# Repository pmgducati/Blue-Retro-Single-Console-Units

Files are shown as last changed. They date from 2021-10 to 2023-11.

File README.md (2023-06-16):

# Blue-Retro-Single-Console-Units

This is a collection of PCBs that I made to work with darthcloud's BlueRetro Project. (https://github.com/darthcloud/BlueRetro) The PCB's were created in Eagle and I have included the Gerbers if you would like to create them yourself.

Currently I have NES, Nintendo 64, Gamecube, Sega Saturn, 3DO, PSX/PS2 and PCEngine/Turbografx 16 complete.

I have created PCB's for other supported systems (Listed Below) but have not tested them as I do not have the sytems. I have created a issue for each of the systems that I do not have to test. If you make one please comment in the related issue on any progress/problems.

I am working through Virtual Boy but need to find a cost efficient way to connect it to the Virtual Boy as I am not consolizing mine.

Here is the current status of all systems:


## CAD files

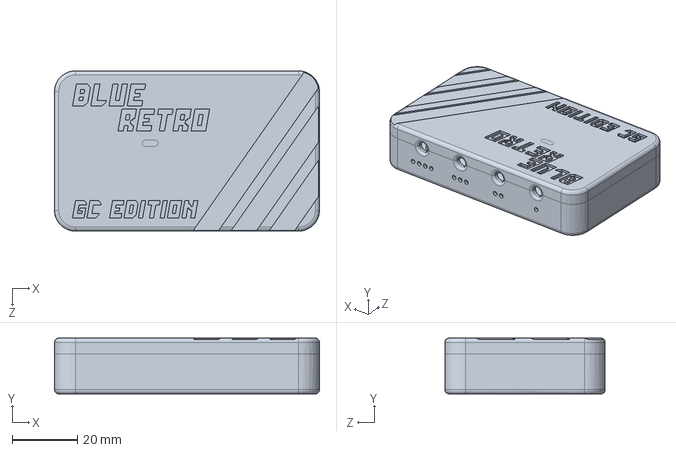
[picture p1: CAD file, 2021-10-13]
CAD/GC Housing - R2.SLDPRT
81.0 x 17.0 x 49.0 mm

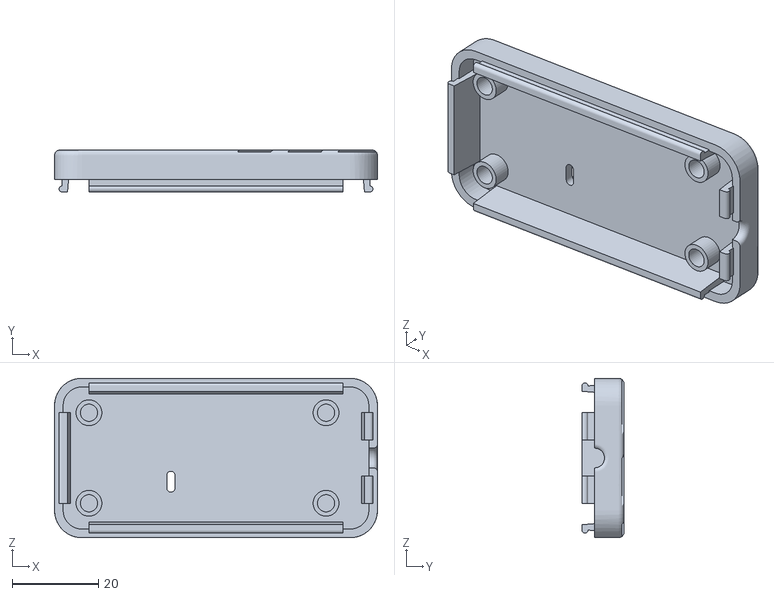
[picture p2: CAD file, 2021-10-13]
STL/3DO Top.STL
74.9 x 9.74 x 37.0

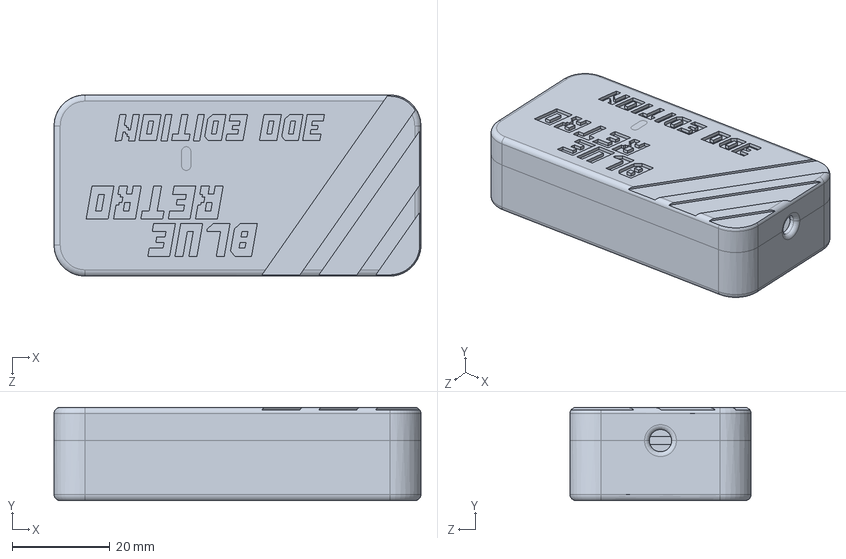
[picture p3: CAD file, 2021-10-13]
CAD/3DO Housing.SLDPRT
74.9 x 19.0 x 37.0 mm

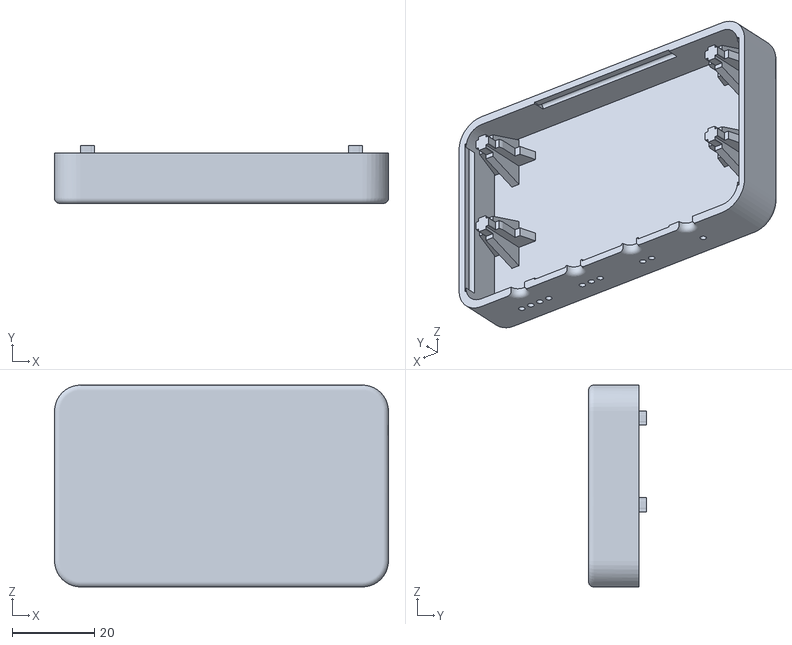
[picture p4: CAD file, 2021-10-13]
STL/GC Bottom.STL
81.0 x 14.0 x 49.0

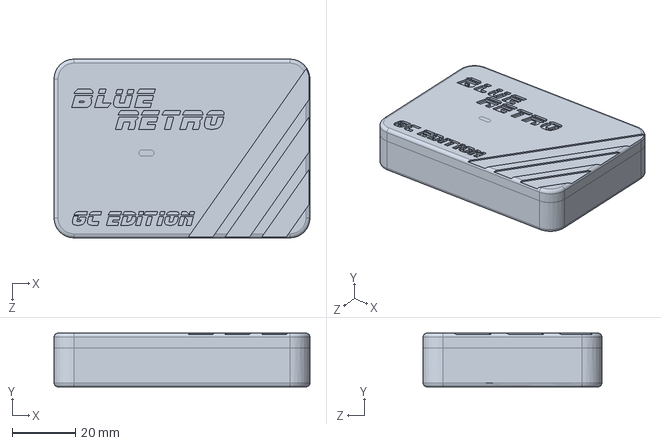
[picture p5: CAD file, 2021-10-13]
CAD/GC Housing.SLDPRT
81.0 x 17.0 x 56.6 mm

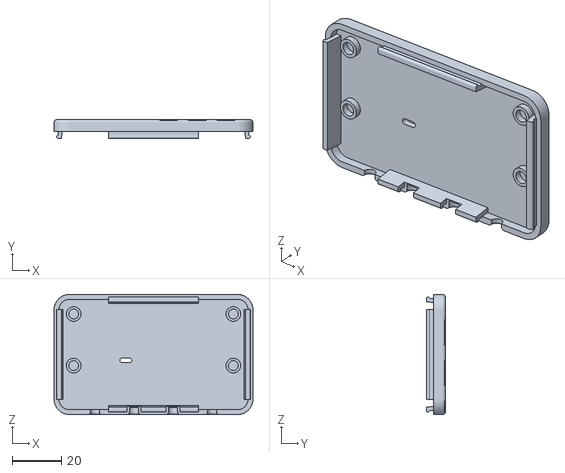
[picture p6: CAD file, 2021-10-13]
STL/GC Top.STL
81.0 x 7.75 x 49.0

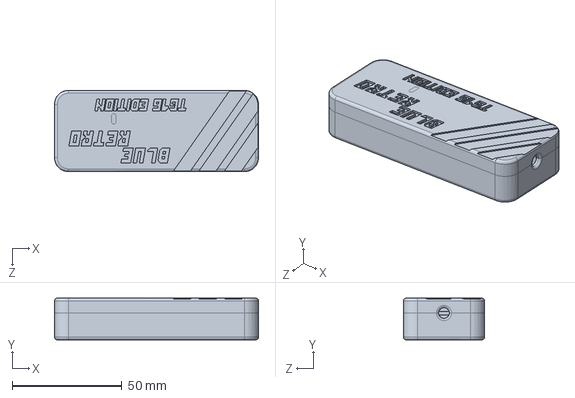
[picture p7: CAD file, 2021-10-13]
CAD/TG-16 Housing.SLDPRT
92.9 x 19.0 x 37.0 mm

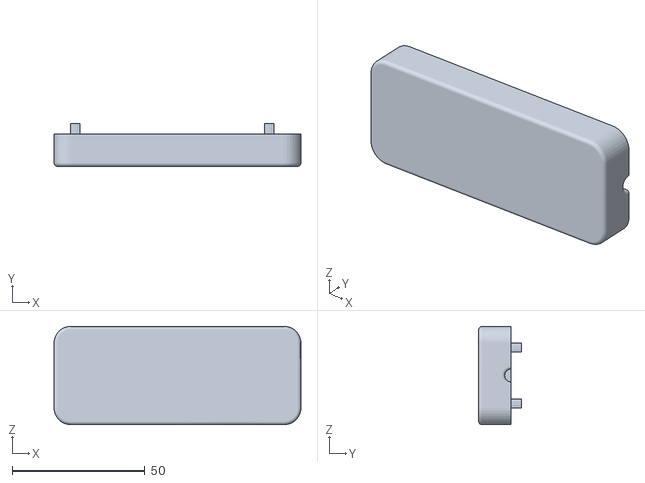
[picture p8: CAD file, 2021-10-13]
STL/TG16 Bottom.STL
92.9 x 16.0 x 37.0

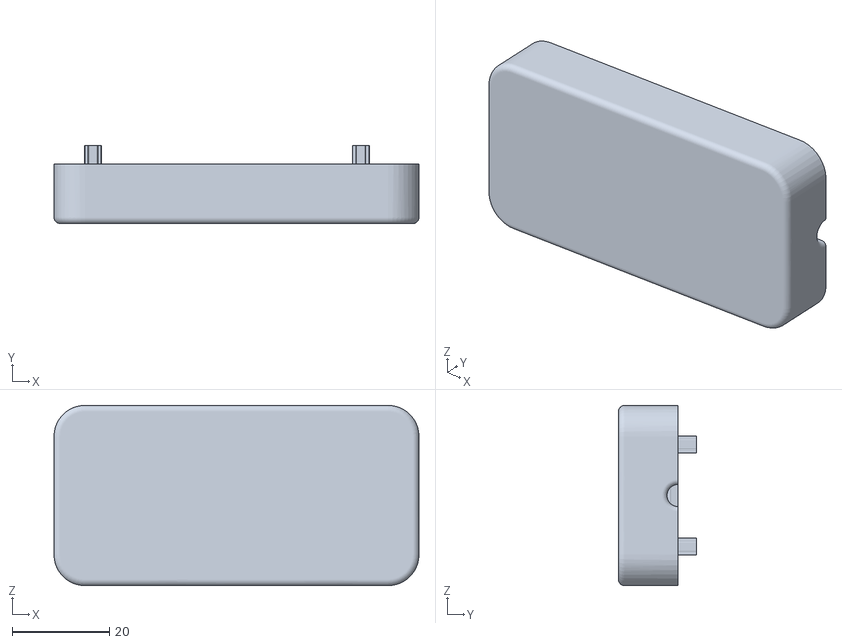
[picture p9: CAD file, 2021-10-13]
STL/3DO Bottom.STL
74.9 x 16.0 x 37.0

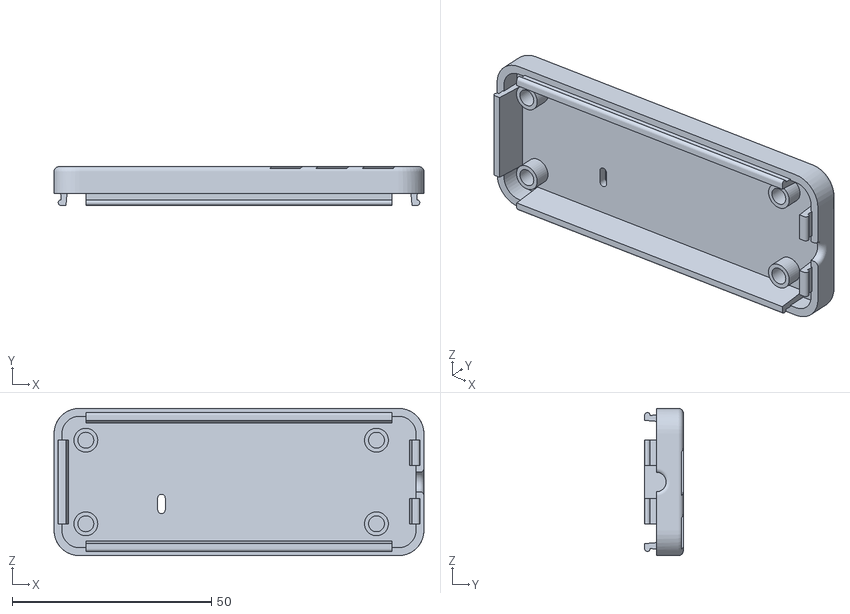
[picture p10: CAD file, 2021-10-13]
STL/TG16 Top.STL
92.9 x 9.74 x 37.0

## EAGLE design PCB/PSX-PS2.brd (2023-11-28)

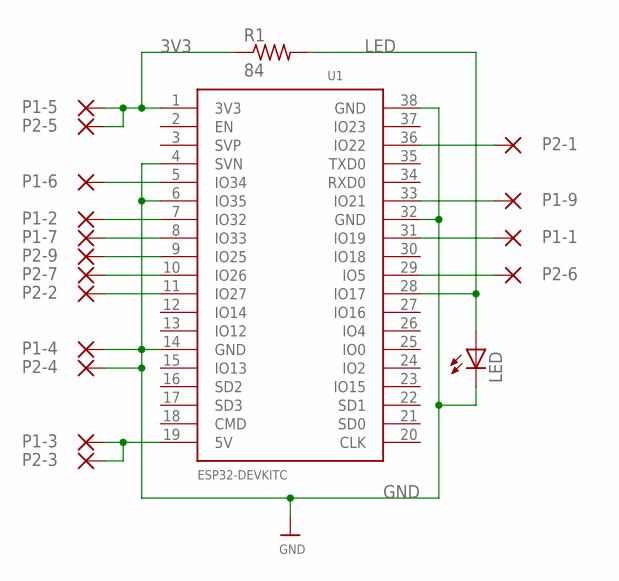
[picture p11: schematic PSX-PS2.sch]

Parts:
LED: LEDCHIPLED_1206; CHIPLED_1206
P1-1, P1-2, P1-3, P1-4, P1-5, P1-6, P1-7, P1-9, P2-1, P2-2, P2-3, P2-4, P2-5, P2-6, P2-7, P2-9: SMD5; SMD2,54-5,08
R1: 84; R1206
U1: ESP32DEVKITC; ESP32-DEVKITC

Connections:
3V3: P1-5.1, P2-5.1, R1.1, U1.1 (3V3)
8V: P1-3.1, P2-3.1, U1.19 (5V)
GND: LED.C, P1-4.1, P2-4.1, U1.4 (SVN), U1.6 (IO35), U1.14 (GND), U1.32 (GND), U1.38 (GND)
LED: LED.A, R1.2, U1.28 (IO17)
P1-1: P1-1.1, U1.31 (IO19)
P1-2: P1-2.1, U1.7 (IO32)
P1-6: P1-6.1, U1.5 (IO34)
P1-7: P1-7.1, U1.8 (IO33)
P1-9: P1-9.1, U1.33 (IO21)
P2-1: P2-1.1, U1.36 (IO22)
P2-2: P2-2.1, U1.11 (IO27)
P2-6: P2-6.1, U1.29 (IO5)
P2-7: P2-7.1, U1.10 (IO26)
P2-9: P2-9.1, U1.9 (IO25)

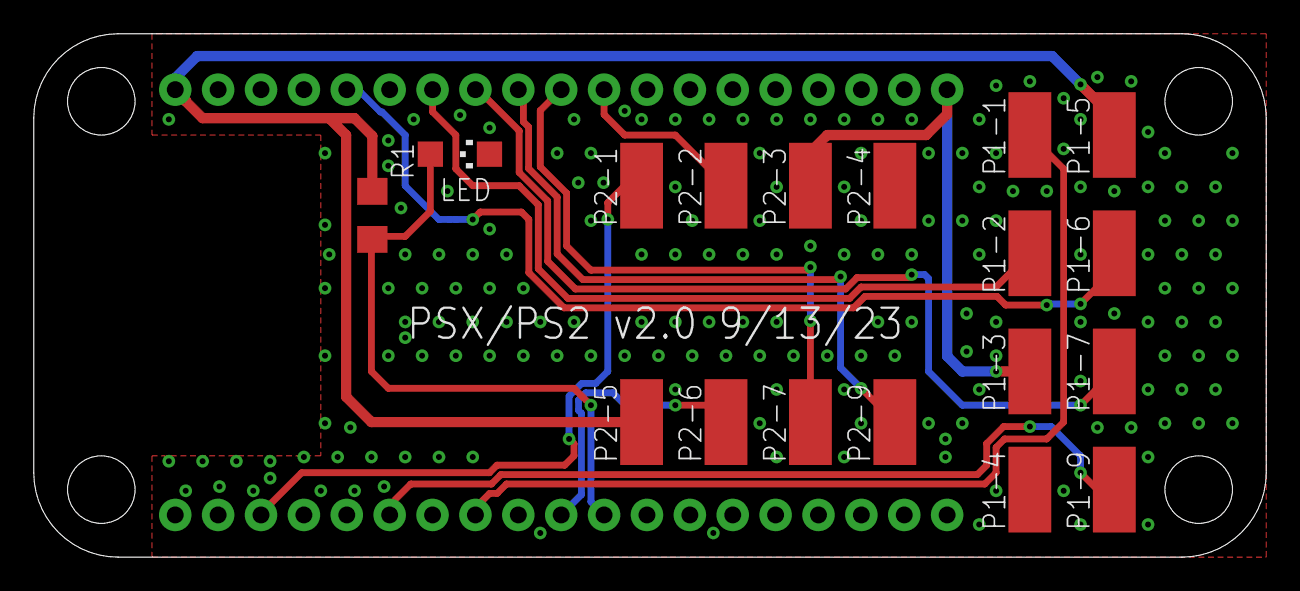
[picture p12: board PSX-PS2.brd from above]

Board: 2 copper layers, 73.0 x 31.0 mm, 19 parts (1 on the bottom side), 14 nets.

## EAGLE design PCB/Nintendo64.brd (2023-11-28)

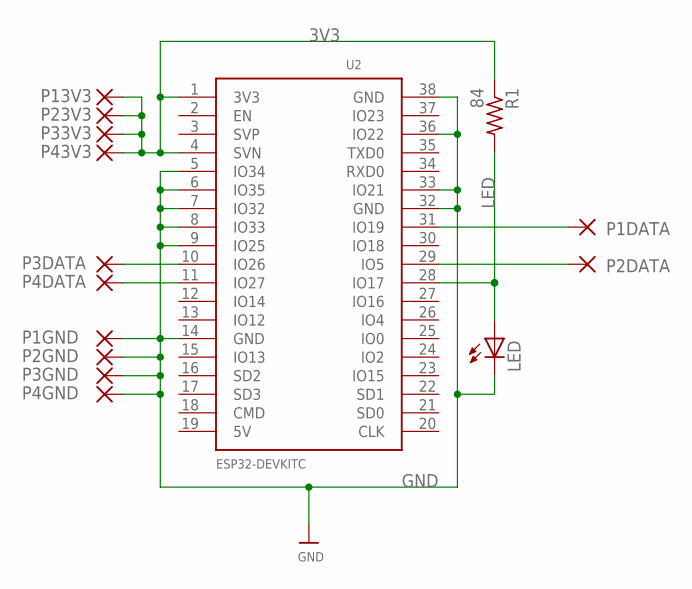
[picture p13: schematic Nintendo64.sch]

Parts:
LED: LEDCHIPLED_1206; CHIPLED_1206
P1DATA, P1GND, P2DATA, P2GND, P3DATA, P3GND, P4DATA, P4GND, P13V3, P23V3, P33V3, P43V3: SMD5; SMD2,54-5,08
R1: 84; R1206
U2: ESP32DEVKITC; ESP32-DEVKITC

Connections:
3V3: P13V3.1, P23V3.1, P33V3.1, P43V3.1, R1.1, U2.1 (3V3), U2.4 (SVN)
GND: LED.C, P1GND.1, P2GND.1, P3GND.1, P4GND.1, U2.5 (IO34), U2.6 (IO35), U2.7 (IO32), U2.8 (IO33), U2.9 (IO25), U2.14 (GND), U2.32 (GND), U2.33 (IO21), U2.36 (IO22), U2.38 (GND)
LED: LED.A, R1.2, U2.28 (IO17)
P1DATA: P1DATA.1, U2.31 (IO19)
P2DATA: P2DATA.1, U2.29 (IO5)
P3DATA: P3DATA.1, U2.10 (IO26)
P4DATA: P4DATA.1, U2.11 (IO27)

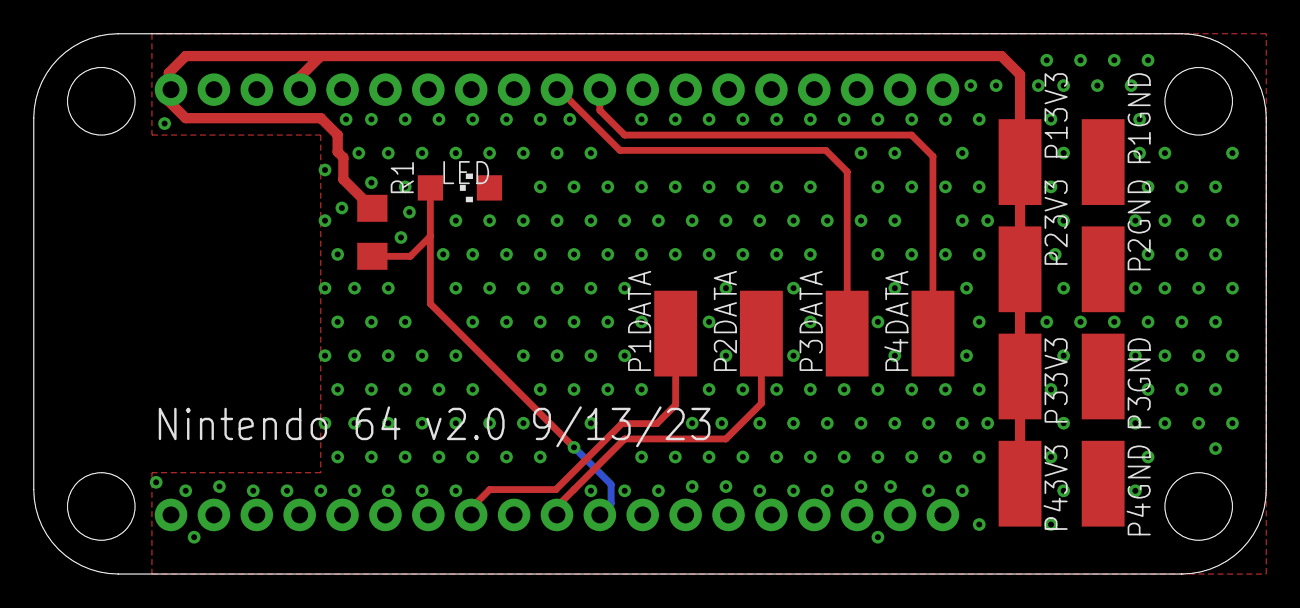
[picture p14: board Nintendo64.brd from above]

Board: 2 copper layers, 73.0 x 32.0 mm, 15 parts (1 on the bottom side), 7 nets.

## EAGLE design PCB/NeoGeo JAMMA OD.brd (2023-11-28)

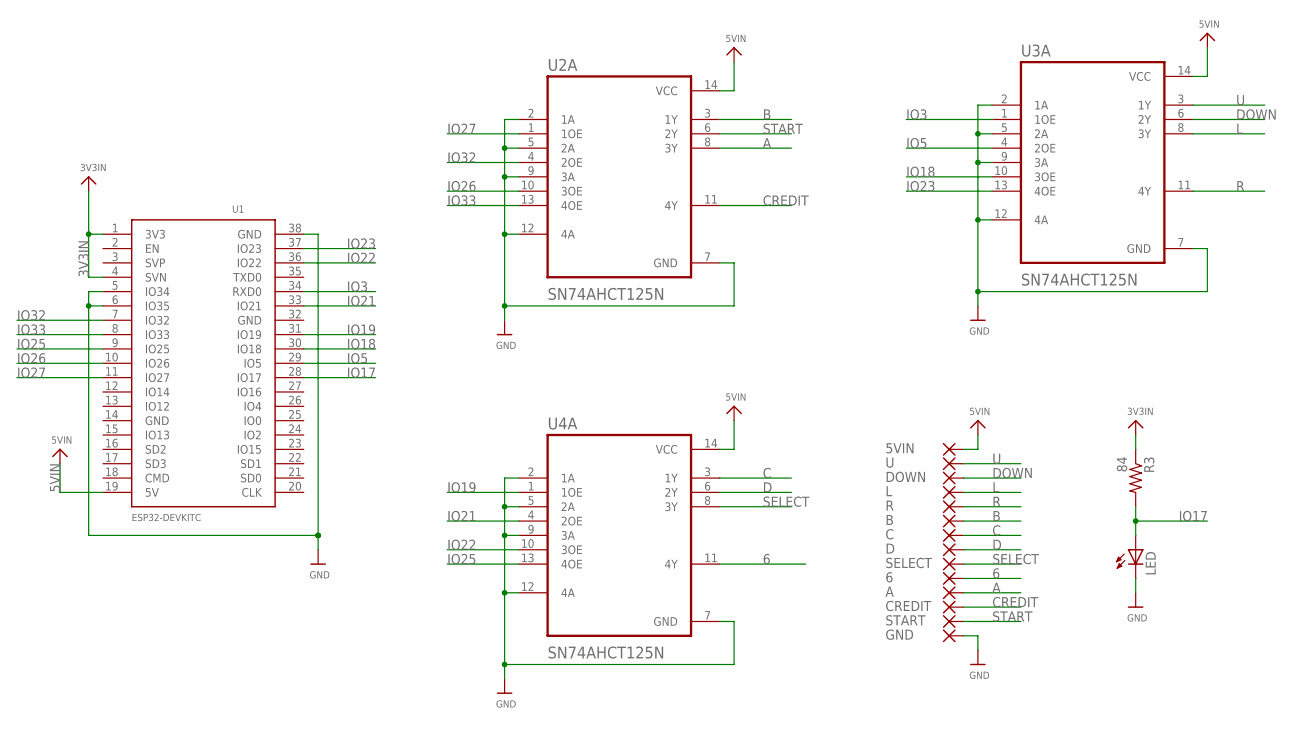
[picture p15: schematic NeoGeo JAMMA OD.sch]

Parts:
5VIN, 6: SMD5; SMD2,54-5,08
A: SMD5; SMD2,54-5,08
B: SMD5; SMD2,54-5,08
C: SMD5; SMD2,54-5,08
CREDIT: SMD5; SMD2,54-5,08
D: SMD5; SMD2,54-5,08
DOWN: SMD5; SMD2,54-5,08
GND: SMD5; SMD2,54-5,08
L: SMD5; SMD2,54-5,08
LED: LEDCHIPLED_1206; CHIPLED_1206
R: SMD5; SMD2,54-5,08
R3: 84; R1206
SELECT: SMD5; SMD2,54-5,08
START: SMD5; SMD2,54-5,08
U: SMD5; SMD2,54-5,08
U1: ESP32DEVKITC; ESP32-DEVKITC
U2A, U3A, U4A: SN74AHCT125N; DIP794W45P254L1969H508Q14

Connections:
3V3IN: R3.1, U1.1 (3V3), U1.4 (SVN)
5VIN: 5VIN.1, U1.19 (5V), U2A.14 (VCC), U3A.14 (VCC), U4A.14 (VCC)
6: 6.1, U4A.11 (4Y)
A: A.1, U2A.8 (3Y)
B: B.1, U2A.3 (1Y)
C: C.1, U4A.3 (1Y)
CREDIT: CREDIT.1, U2A.11 (4Y)
D: D.1, U4A.6 (2Y)
DOWN: DOWN.1, U3A.6 (2Y)
GND: GND.1, LED.C, U1.5 (IO34), U1.6 (IO35), U1.38 (GND), U2A.2 (1A), U2A.5 (2A), U2A.7 (GND), U2A.9 (3A), U2A.12 (4A), U3A.2 (1A), U3A.5 (2A), U3A.7 (GND), U3A.9 (3A), U3A.12 (4A), U4A.2 (1A), U4A.5 (2A), U4A.7 (GND), U4A.9 (3A), U4A.12 (4A)
IO3: U1.34 (RXD0), U3A.1 (1OE)
IO5: U1.29 (IO5), U3A.4 (2OE)
IO17: LED.A, R3.2, U1.28 (IO17)
IO18: U1.30 (IO18), U3A.10 (3OE)
IO19: U1.31 (IO19), U4A.1 (1OE)
IO21: U1.33 (IO21), U4A.4 (2OE)
IO22: U1.36 (IO22), U4A.10 (3OE)
IO23: U1.37 (IO23), U3A.13 (4OE)
IO25: U1.9 (IO25), U4A.13 (4OE)
IO26: U1.10 (IO26), U2A.10 (3OE)
IO27: U1.11 (IO27), U2A.1 (1OE)
IO32: U1.7 (IO32), U2A.4 (2OE)
IO33: U1.8 (IO33), U2A.13 (4OE)
L: L.1, U3A.8 (3Y)
R: R.1, U3A.11 (4Y)
SELECT: SELECT.1, U4A.8 (3Y)
START: START.1, U2A.6 (2Y)
U: U.1, U3A.3 (1Y)

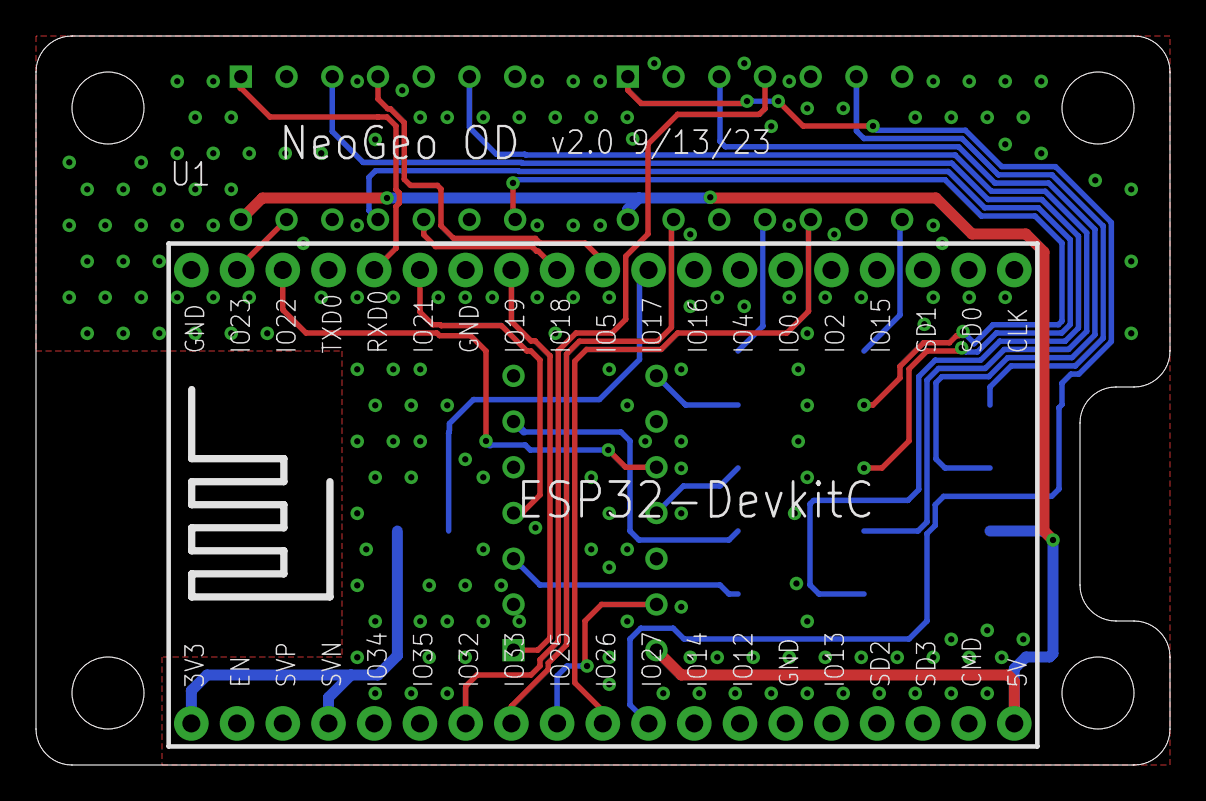
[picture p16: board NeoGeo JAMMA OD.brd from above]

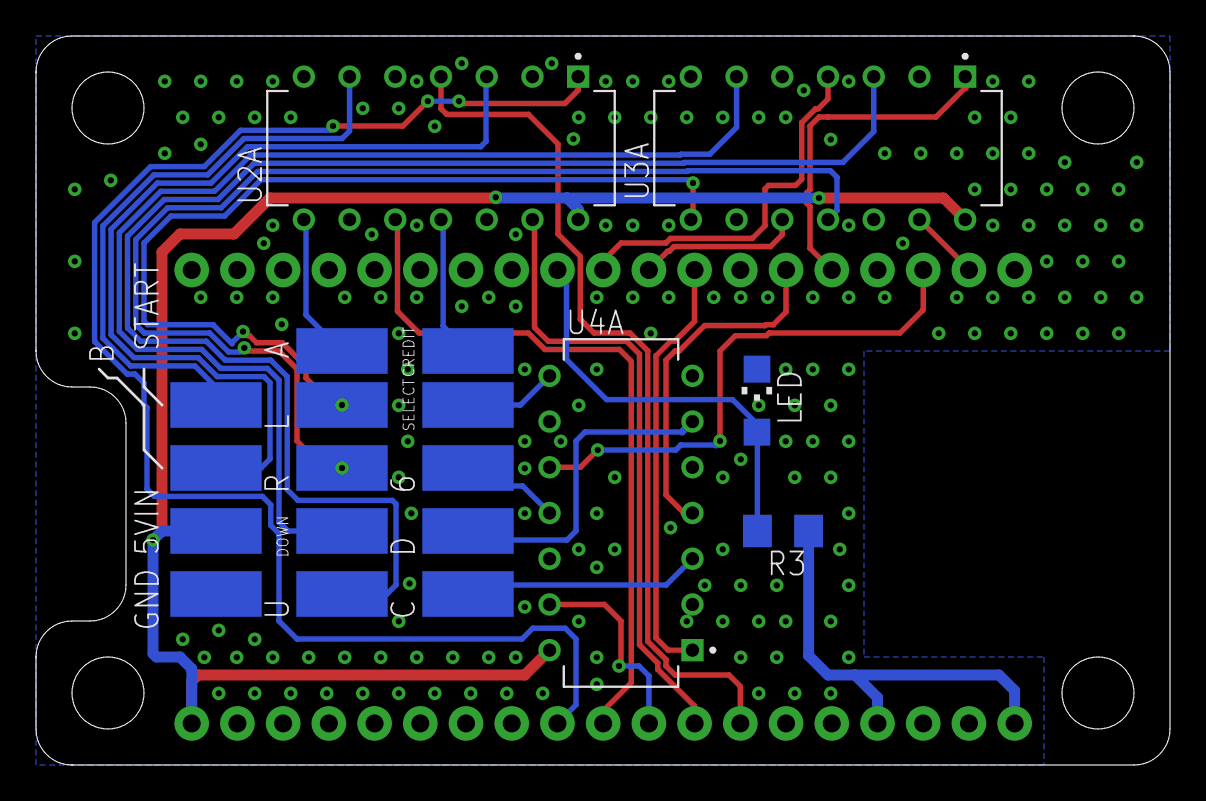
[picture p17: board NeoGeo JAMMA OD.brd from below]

Board: 2 copper layers, 63.0 x 40.5 mm, 20 parts (19 on the bottom side), 28 nets.

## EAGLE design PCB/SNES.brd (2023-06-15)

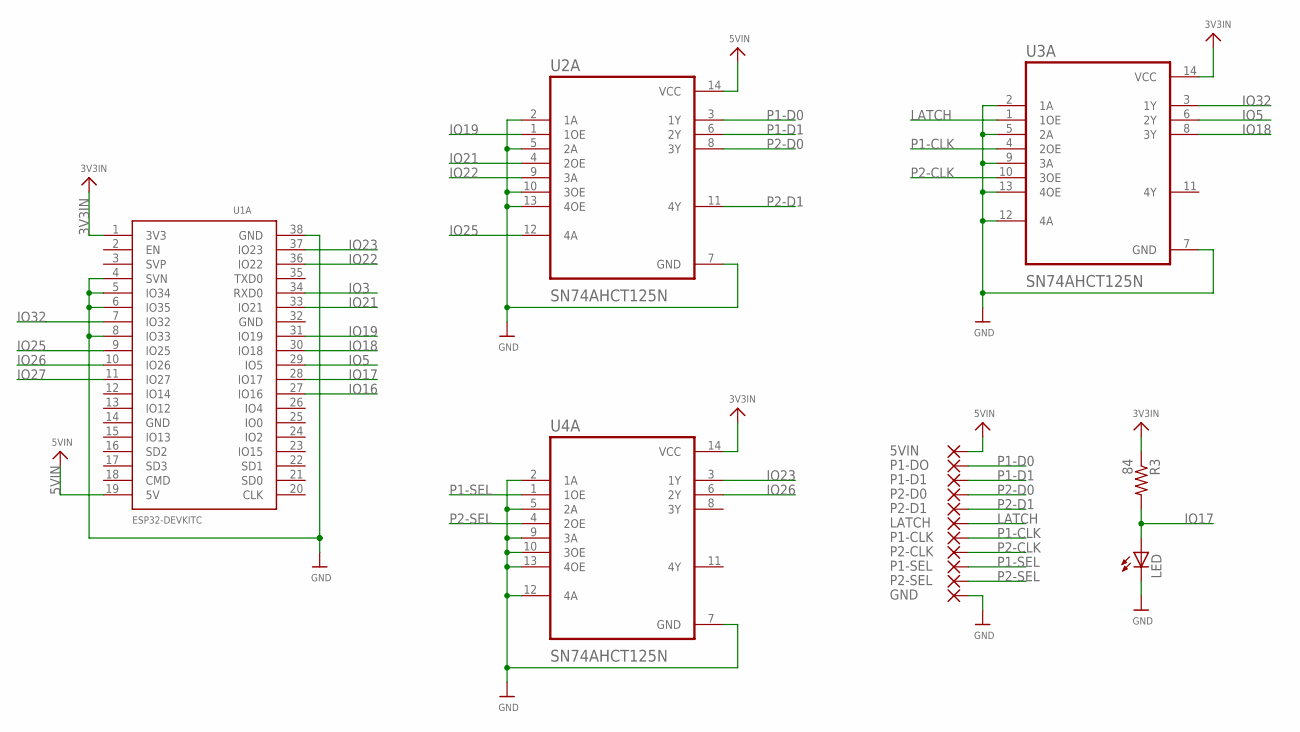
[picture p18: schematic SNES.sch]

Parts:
5VIN: SMD5; SMD2,54-5,08
GND: SMD5; SMD2,54-5,08
LATCH: SMD5; SMD2,54-5,08
LED: LEDCHIPLED_1206; CHIPLED_1206
P1-CLK, P1-D1, P1-DO, P1-SEL, P2-CLK, P2-D0, P2-D1, P2-SEL: SMD5; SMD2,54-5,08
R3: 84; R1206
U1A: ESP32DEVKITC; ESP32-DEVKITC
U2A, U3A, U4A: SN74AHCT125N; DIP794W45P254L1969H508Q14

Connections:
3V3IN: R3.1, U1A.1 (3V3), U3A.14 (VCC), U4A.14 (VCC)
5VIN: 5VIN.1, U1A.19 (5V), U2A.14 (VCC)
GND: GND.1, LED.C, U1A.4 (SVN), U1A.5 (IO34), U1A.6 (IO35), U1A.8 (IO33), U1A.38 (GND), U2A.2 (1A), U2A.5 (2A), U2A.7 (GND), U2A.10 (3OE), U2A.13 (4OE), U3A.2 (1A), U3A.5 (2A), U3A.7 (GND), U3A.9 (3A), U3A.12 (4A), U3A.13 (4OE), U4A.2 (1A), U4A.5 (2A), U4A.7 (GND), U4A.9 (3A), U4A.10 (3OE), U4A.12 (4A), U4A.13 (4OE)
IO3: U1A.34 (RXD0)
IO5: U1A.29 (IO5), U3A.6 (2Y)
IO16: U1A.27 (IO16)
IO17: LED.A, R3.2, U1A.28 (IO17)
IO18: U1A.30 (IO18), U3A.8 (3Y)
IO19: U1A.31 (IO19), U2A.1 (1OE)
IO21: U1A.33 (IO21), U2A.4 (2OE)
IO22: U1A.36 (IO22), U2A.9 (3A)
IO23: U1A.37 (IO23), U4A.3 (1Y)
IO25: U1A.9 (IO25), U2A.12 (4A)
IO26: U1A.10 (IO26), U4A.6 (2Y)
IO27: U1A.11 (IO27)
IO32: U1A.7 (IO32), U3A.3 (1Y)
LATCH: LATCH.1, U3A.1 (1OE)
P1-CLK: P1-CLK.1, U3A.4 (2OE)
P1-D0: P1-DO.1, U2A.3 (1Y)
P1-D1: P1-D1.1, U2A.6 (2Y)
P1-SEL: P1-SEL.1, U4A.1 (1OE)
P2-CLK: P2-CLK.1, U3A.10 (3OE)
P2-D0: P2-D0.1, U2A.8 (3Y)
P2-D1: P2-D1.1, U2A.11 (4Y)
P2-SEL: P2-SEL.1, U4A.4 (2OE)

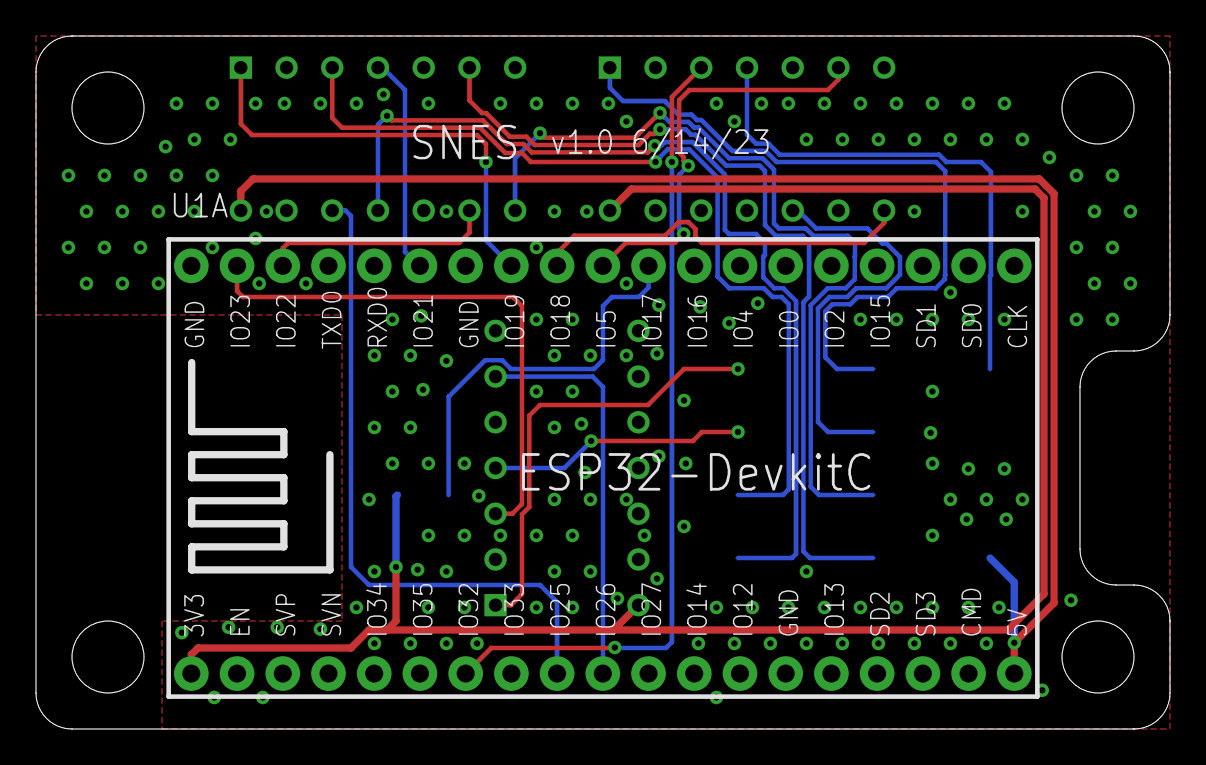
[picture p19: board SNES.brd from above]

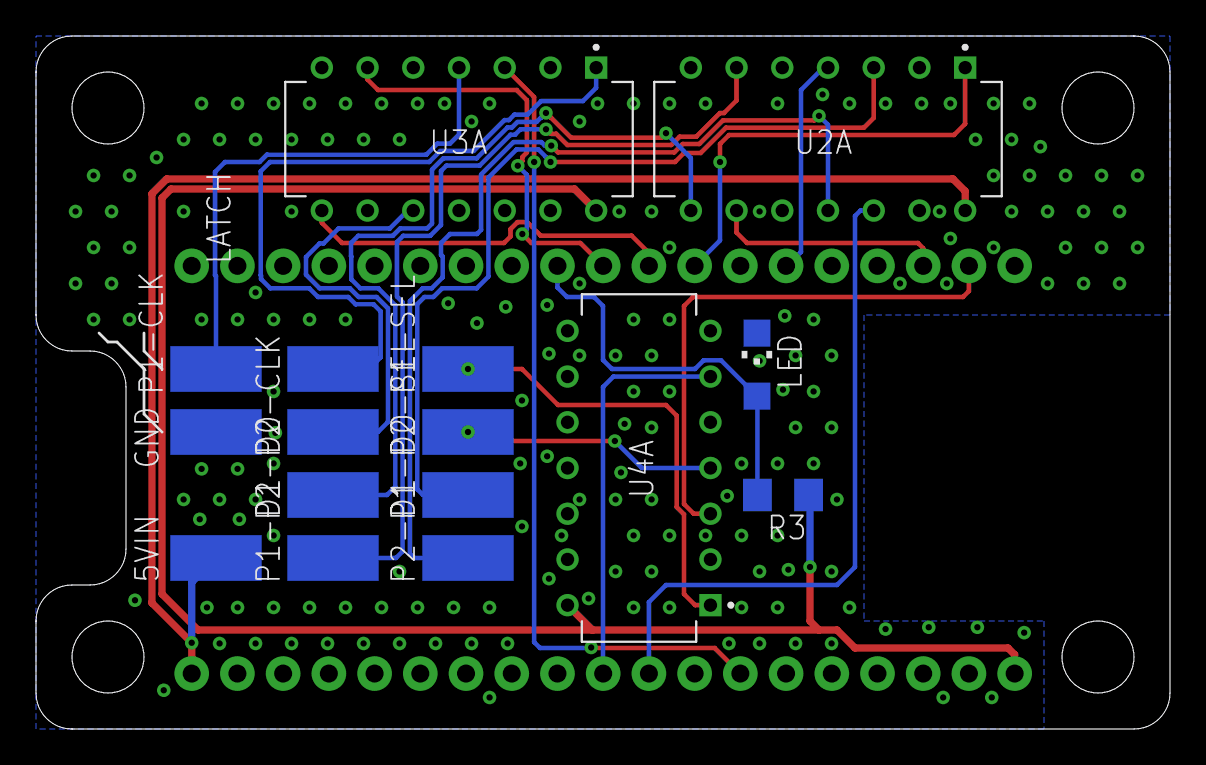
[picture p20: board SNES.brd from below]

Board: 2 copper layers, 63.0 x 38.5 mm, 17 parts (16 on the bottom side), 22 nets.

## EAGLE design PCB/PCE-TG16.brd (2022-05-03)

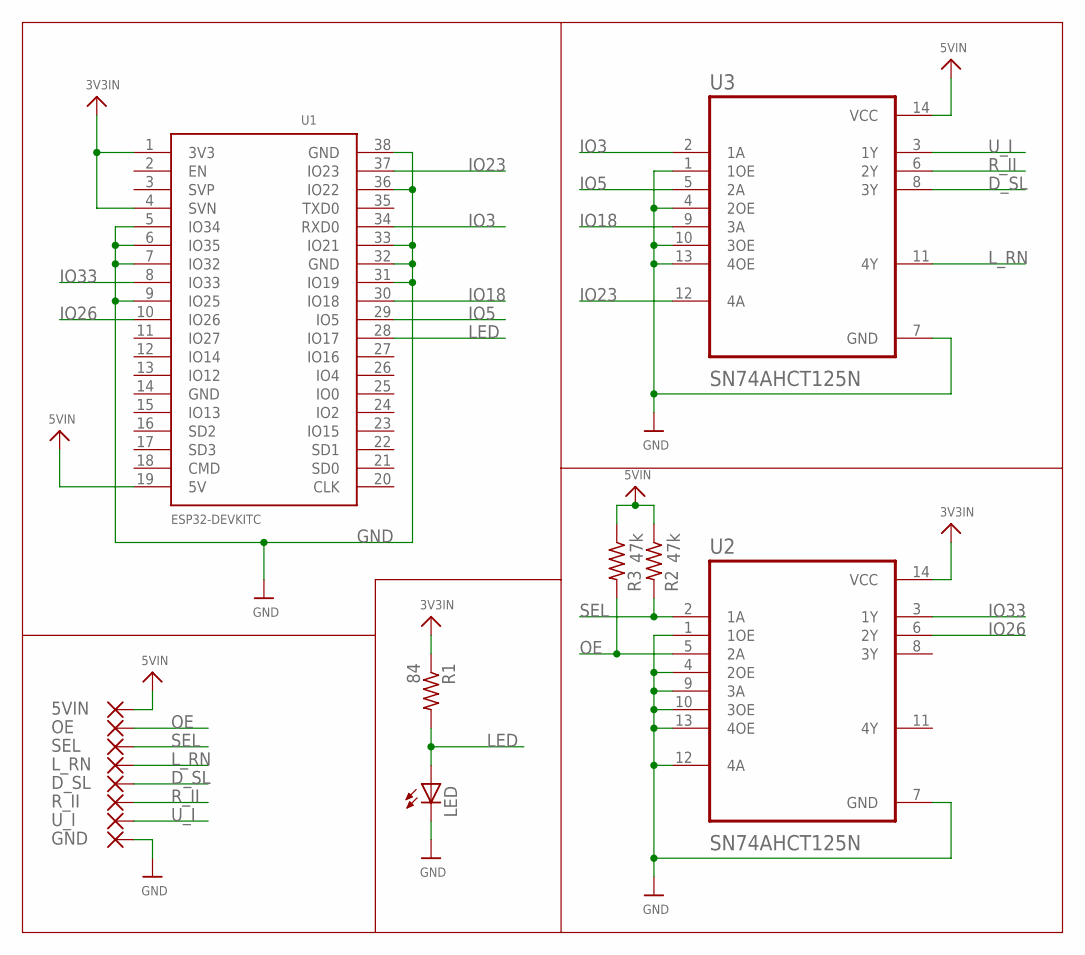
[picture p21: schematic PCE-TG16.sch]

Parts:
5VIN: SMD5; SMD2,54-5,08
D_SL: SMD5; SMD2,54-5,08
GND: SMD5; SMD2,54-5,08
LED: LEDCHIPLED_1206; CHIPLED_1206
L_RN: SMD5; SMD2,54-5,08
OE: SMD5; SMD2,54-5,08
R1: 84; R1206
R2, R3: 47k; R1206
R_II: SMD5; SMD2,54-5,08
SEL: SMD5; SMD2,54-5,08
U1: ESP32DEVKITC; ESP32-DEVKITC
U2, U3: SN74AHCT125N; DIP794W45P254L1969H508Q14
U_I: SMD5; SMD2,54-5,08

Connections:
3V3IN: R1.1, U1.1 (3V3), U1.4 (SVN), U2.14 (VCC)
5VIN: 5VIN.1, R2.1, R3.1, U1.19 (5V), U3.14 (VCC)
D_SL: D_SL.1, U3.8 (3Y)
GND: GND.1, LED.C, U1.5 (IO34), U1.6 (IO35), U1.7 (IO32), U1.9 (IO25), U1.31 (IO19), U1.32 (GND), U1.33 (IO21), U1.36 (IO22), U1.38 (GND), U2.1 (1OE), U2.4 (2OE), U2.7 (GND), U2.9 (3A), U2.10 (3OE), U2.12 (4A), U2.13 (4OE), U3.1 (1OE), U3.4 (2OE), U3.7 (GND), U3.10 (3OE), U3.13 (4OE)
IO3: U1.34 (RXD0), U3.2 (1A)
IO5: U1.29 (IO5), U3.5 (2A)
IO18: U1.30 (IO18), U3.9 (3A)
IO23: U1.37 (IO23), U3.12 (4A)
IO26: U1.10 (IO26), U2.6 (2Y)
IO33: U1.8 (IO33), U2.3 (1Y)
LED: LED.A, R1.2, U1.28 (IO17)
L_RN: L_RN.1, U3.11 (4Y)
OE: OE.1, R3.2, U2.5 (2A)
R_II: R_II.1, U3.6 (2Y)
SEL: R2.2, SEL.1, U2.2 (1A)
U_I: U3.3 (1Y), U_I.1

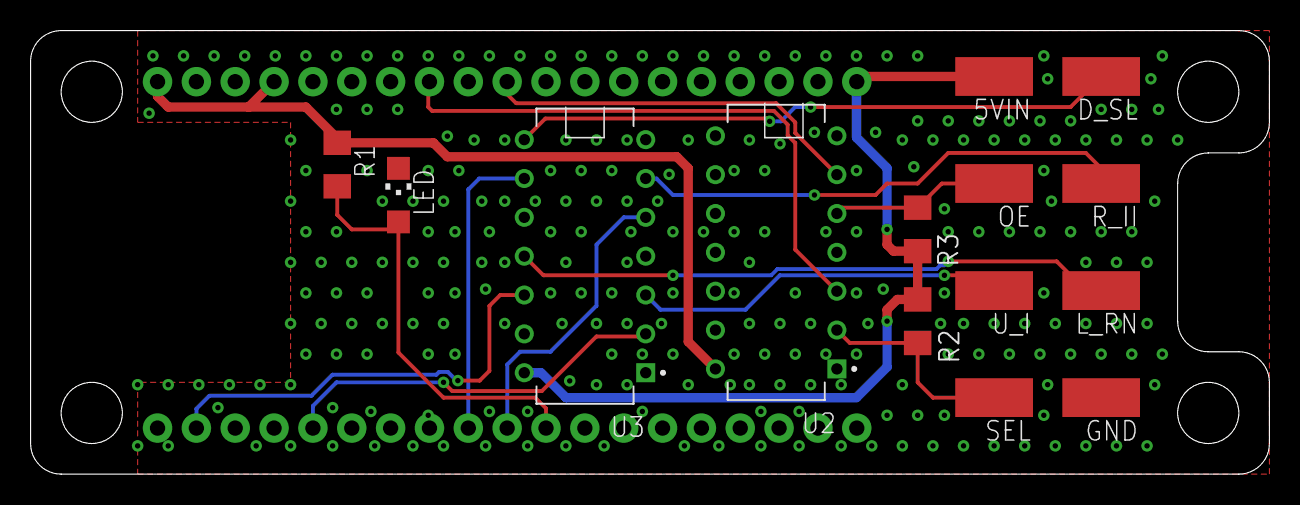
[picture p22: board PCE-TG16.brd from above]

Board: 2 copper layers, 81.0 x 29.0 mm, 15 parts (1 on the bottom side), 16 nets.

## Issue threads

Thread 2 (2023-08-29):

Neo Geo OD

pmgducati, 2023-08-29:
Please put testing results here

pmgducati, 2023-08-29:
https://github.com/pmgducati/Blue-Retro-Single-Console-Units/tree/Neo-Geo-OD

tr12345, 2023-09-13:
I have these PCB's on order, it looks like they should be here this week or early next week.  I was looking at the board inside the Eagle software and it seems like the holes for the ESP32 module are closer together when compared to the main board.  I could be wrong but it looks like they are only 22mm apart while if you compare it to the main board it is closer to 25 mm apart.  Am I seeing that right?

pmgducati, 2023-09-13:
Hey,
I apologize the library I used was an old one from when I was using the node mcu esp32 for this project.  I thought I changed everything and removed the library.  Which I did do for the AIO verision.  I need to revist all the PCBs in this repo and update them.

I have updated the PCB and added the gerber with the standard size ESP32
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

If you want to save some time you can pick up the thinner ESPs on amazon here:
https://www.amazon.com/gp/product/B0718T232Z/ref=ppx_yo_dt_b_search_asin_title?ie=UTF8&psc=1

Here is a link to the issue to update the rest of the repo:
https://github.com/pmgducati/Blue-Retro-Single-Console-Units/issues/3

Commit:
https://github.com/pmgducati/Blue-Retro-Single-Console-Units/commit/5b00320c25f350a8290d436fb3a91411caf1505d

tr12345, 2023-09-13:
no worries, I already have the ESP32 modules so I plan on just ordering the updated board.   I hade some other boards I wanted to order anyways.  Thank you for the super fast update!

pmgducati, 2023-09-14:
Hold off ordering them, I got about half done updating to the correct
footprint. I'm planning on wrapping up the rest this weekend. While I'm
working in there. Are there any systems that aren't done yet that you would
like?

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

tr12345, 2023-09-14:
I plan to just make two all in one Neo Geo adapters and then one adapter running the universal software for all my other systems.  I already ordered Saturn and Genesis PCBs.  I was working on a PCB design for N64 and Dreamcast that included switches for turning off Player 2, 3, or 4.  This is what I had so far for N64, would love your feedback on the design if you have time.

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
[Gerber_Nintendo 64 With Switches_2023-09-13.zip](https://github.com/pmgducati/Blue-Retro-Single-Console-Units/files/12604500/Gerber_Nintendo.64.With.Switches_2023-09-13.zip)

tr12345, 2023-09-14:
Digikey part number for the switches is CKN9542-ND

tr12345, 2023-09-14:
Realized all of a sudden that I wired the switches wrong.  This is the schematic of what I'm wanting to do so that I can redirect the IO pins to 3.3V and disable those ports on the fly.

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

tr12345, 2023-09-14:
Updated Board and Schematic in Eagle
[Eagle - Nintendo 64 With Switches.zip](https://github.com/pmgducati/Blue-Retro-Single-Console-Units/files/12614250/Eagle.-.Nintendo.64.With.Switches.zip)

GrumpyGopher, 2023-09-26:
Hey @pmgducati, I finally got those boards in, the ones that are meant for the smaller ESP32.  I was able to get it connected to my ESP32 modules and everything tested ok.  Neo Geo CD does not have a Credit or 6 button so for those I just tested them with a multi-meter

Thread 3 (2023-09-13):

Update ESP to Standard Size

pmgducati, 2023-09-13:
The PCB used in the design originally was the Node MCU ESP32 which is 22mm between the pin rows.  The standard ESP32 has 25mm between rows.  I need to revisit each version to update the part.

- [ ] 3DO
- [ ] Atari 2600 OD
- [ ] Atari 2600 PP
- [ ] CD-i
- [ ] Dreamcast
- [ ] Gamecube
- [ ] Genesis
- [ ] NES
- [ ] Neo Geo JAMMA OD
- [ ] Nintendo 64
- [ ] PC-FX
- [ ] PCE-TG16
- [ ] PSX-PS2
- [ ] SG1000 - SMS OD
- [ ] SG1000 - SMS PP
- [ ] SNES

Thanks @TR12345 for catching this issue on the NeoGeo PCB, Sorry for the inconvenience!

If someone does make the PCBs before they get updated, this ESP will fit:
https://www.amazon.com/gp/product/B0718T232Z/ref=ppx_yo_dt_b_search_asin_title?ie=UTF8&psc=1

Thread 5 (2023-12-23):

3DO Fz-10 (Anvil) adapter hasn't input

CarloScalabrin, 2023-12-23:
Hello everyone, I'm facing some problems to get Blureretro Core to work on the 3DO FZ-10 with Anvil chip. I am using your pmgducati's PCB design. On Fz-1 and Fz-10 with DSP Clio it works normally, however on Fz-10 models with DSP Anvil, it does not work. The core has power, the control pairs normally, but there is no button input. Any tips/suggestions?

pmgducati, 2023-12-23:
Hi @CarloScalabrin!

I have an anvil FZ-10, I haven't used it in a long time as my FZ1 is my main unit.  I will dig into it after Christmas when I'm back at the house.

CarloScalabrin, 2023-12-23:
Great!!! Thanks for your help @pmgducati !!!!

CarloScalabrin, 2024-01-07:
Hello @pmgducati did you have time to see if on your anvil's 3DO works? Thanks.

pmgducati, 2024-01-11:
Sorry for the Delay, I am seeing the same behavior.  Most likely this is an issue with Blueretro itself.  you should raise an issue in that repo.

https://github.com/darthcloud/BlueRetro/issues

CarloScalabrin, 2024-01-11:
> Sorry for the Delay, I am seeing the same behavior.  Most likely this is an issue with Blueretro itself.  you should raise an issue in that repo.
>
> https://github.com/darthcloud/BlueRetro/issues

No problem. Thanks for your help @pmgducati

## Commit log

2021-10-13 Initial Upload
    [3DO Bottom.STL, 3DO Housing.SLDPRT, 3DO Top.STL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]
2022-05-03 New PCBs & House Keeping
    Created New PCBs for Atari 2600 (PP/OD), CD-i, Dreamcast, NES, N64, PC-FX and PSX/PS2.
    Rearranged files to better match AIO Repo
    [3DO Bottom.STL, 3DO Top.STL, Atari 2600 OD.brd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]
2023-06-15 New PCB Versions
    Adding SG-1000/SMS, SNES and Genesis (Per PCESlayer's Request). Eagle Files and Gerbers are included. BOM has been removed and can be referenced in the AIO repository.
    [Genesis.brd, Genesis.sch, Project Status.xlsx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]
2023-06-16 Genesis Gerber
    Adding the Genesis Gerber file. It was missed in the last commit
2023-08-29 Neo Geo OD Standalone
    Create per tr12345's request in the AIO thread
    [NeoGeo JAMMA OD.brd, NeoGeo JAMMA OD.sch]
2023-08-29 Updated Project Status
    [Project Status.xlsx]
2023-09-13 ESP Size Change
    The original design used an ESP with a 22mm spacing, Updated the part to the standard version with 25mm spacing.
    [NeoGeo JAMMA OD.brd, NeoGeo JAMMA OD.sch]
2023-09-13 Update version Callout and date on PCB
    [NeoGeo JAMMA OD.brd]
2023-11-28 Updated PCBs
    [Dreamcast.brd, Dreamcast.sch, Nintendo64.brd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]

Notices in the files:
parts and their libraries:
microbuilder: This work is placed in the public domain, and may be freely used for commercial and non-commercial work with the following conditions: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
